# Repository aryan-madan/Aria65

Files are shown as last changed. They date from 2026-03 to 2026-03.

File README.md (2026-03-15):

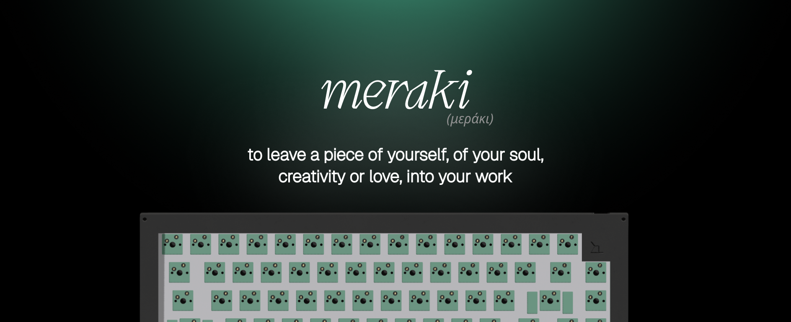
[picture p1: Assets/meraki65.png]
Banner


<p>
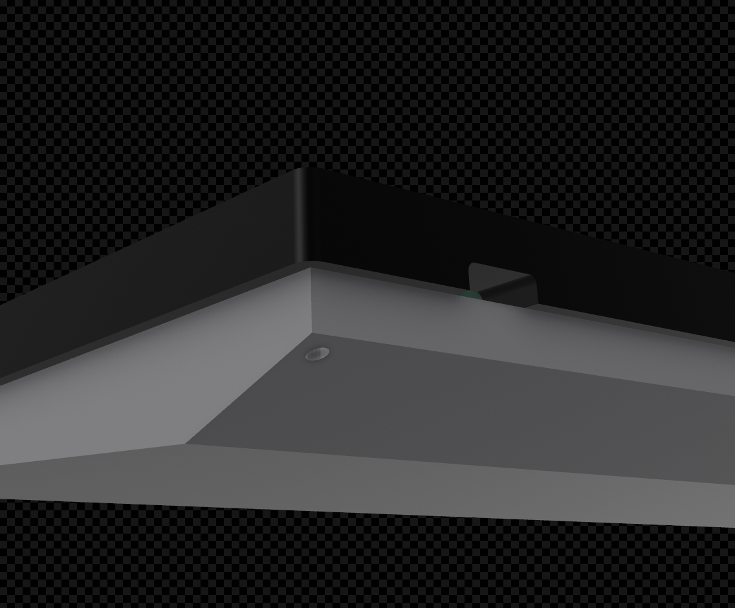
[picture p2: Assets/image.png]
  
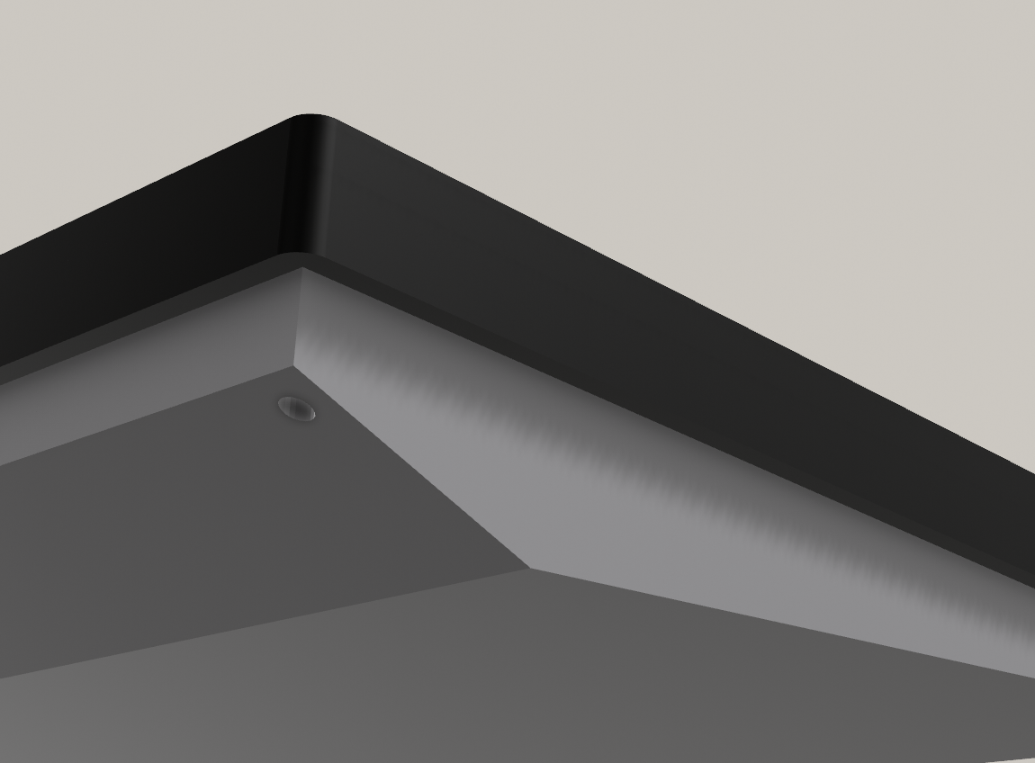
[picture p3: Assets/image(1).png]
  
</p>

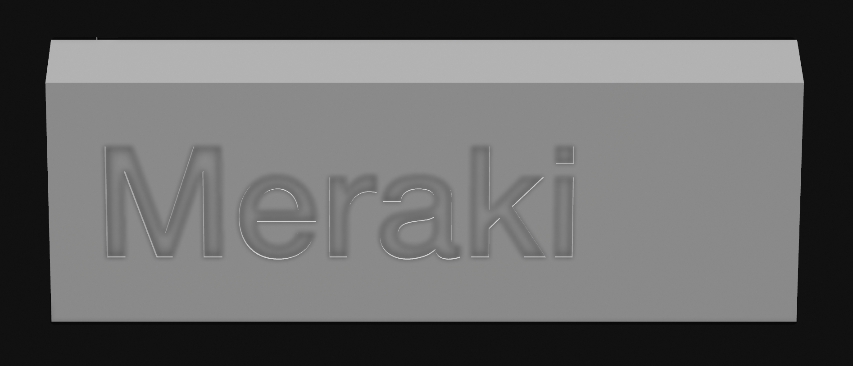
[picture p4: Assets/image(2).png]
Bottom


<p>
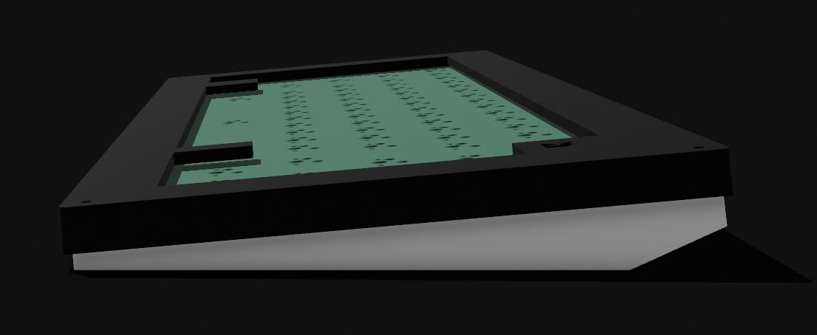
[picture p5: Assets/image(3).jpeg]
  
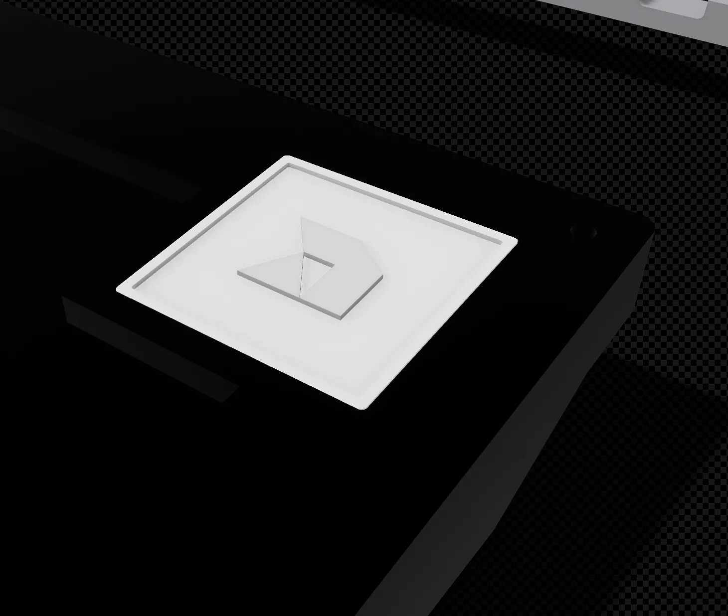
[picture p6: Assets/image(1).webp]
  
</p>

# Name

Meraki, is a greek word that means 'to do something with soul, creativity, or love; leaving a piece of yourself in what you do'.

# Layout 

The keyboard has a 65% WKL Layout. WKL stands for win-key-less, where the Windows key is removed from the keyboard, to give it a more symmetrical shape. WKL's are rarely seen in 65% form, which inspired me to make this board. I also opted for a blocker at the top right to fit the MCU.

# Firmware

The Meraki65 uses qmk for its firmware.
I also created a web-based software to re-map keys, called [Keydeck](https://keydeck.xyz).

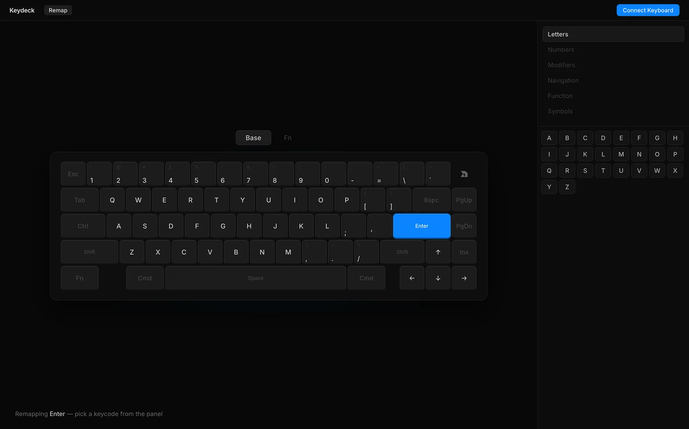
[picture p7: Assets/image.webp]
Keydeck Software


# PCB

## Schematic

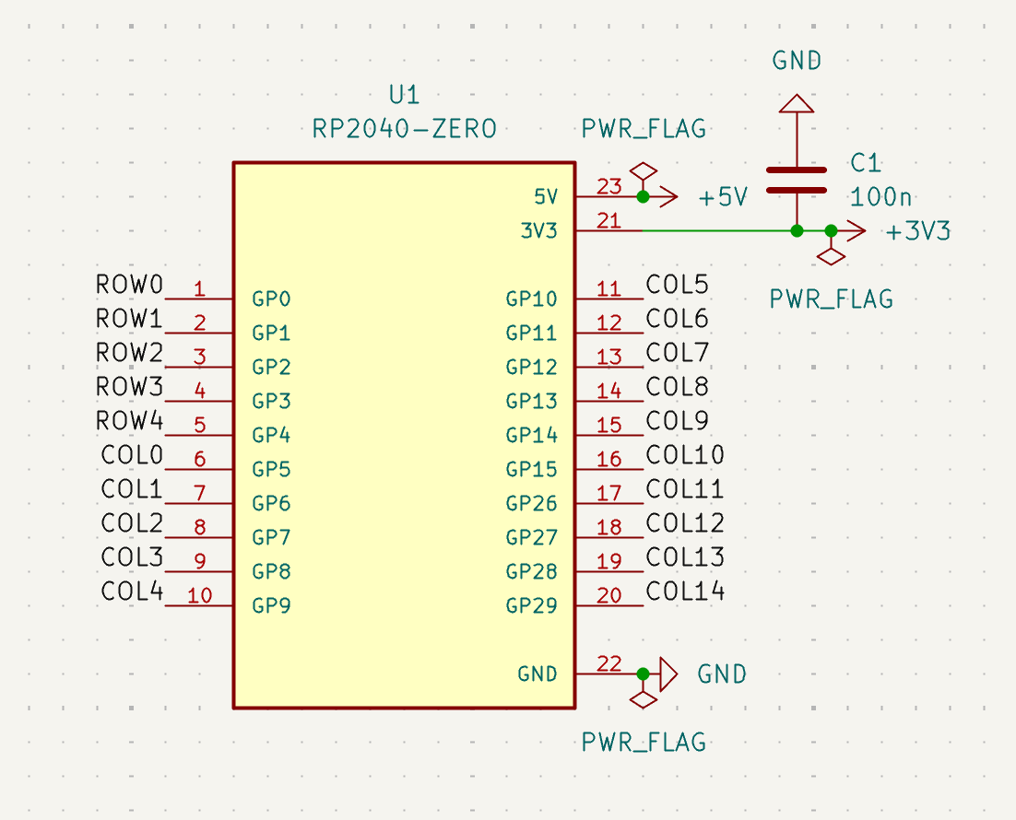
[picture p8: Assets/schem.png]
Schematic


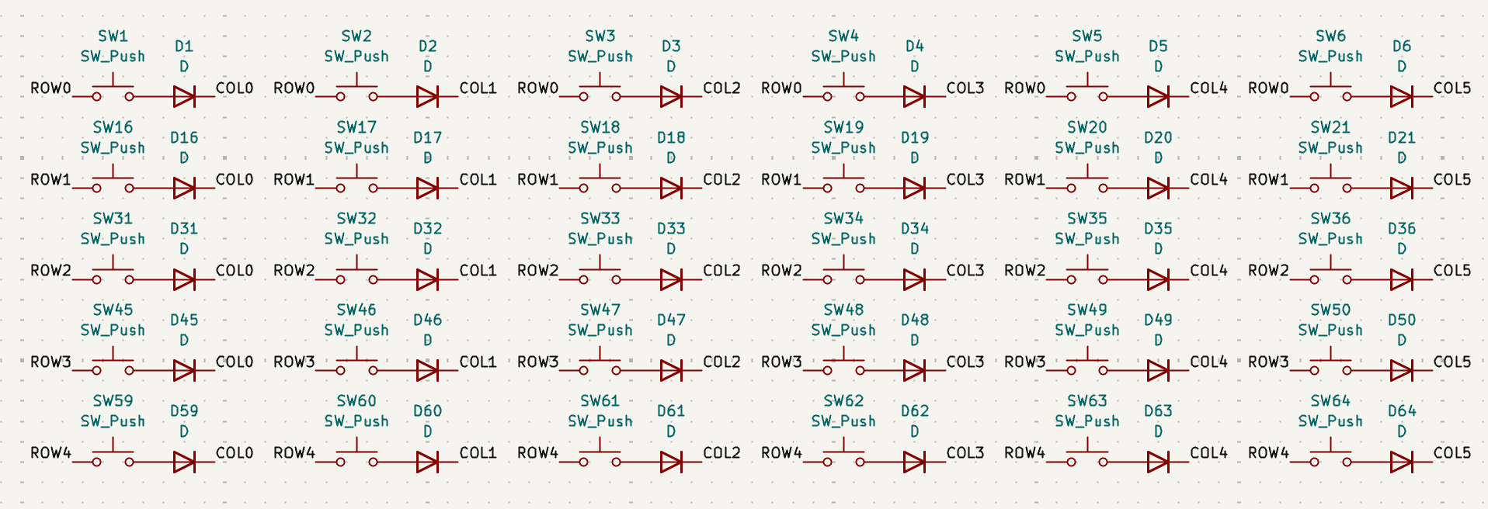
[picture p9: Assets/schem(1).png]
Schematic 2


## PCB

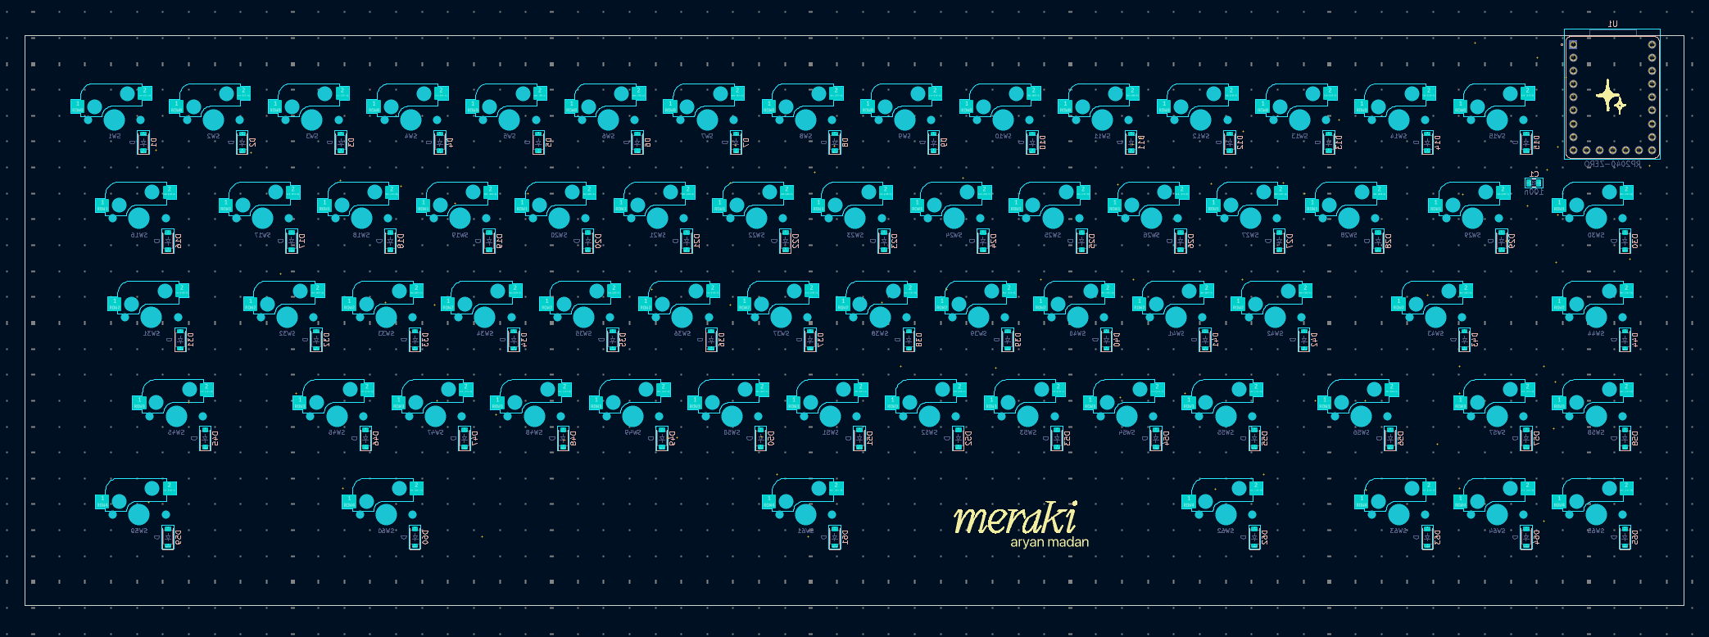
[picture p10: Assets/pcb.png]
PCB


# Bill of Materials

Total Cost: **9,792** (~$106.38 USD)

## Case

https://app.shapr3d.com/v/_-Txvu9VtqTR88f_0C18B

To be 3d printed by the Printing Legion.

## Parts

| Piece | Brand | Quantity | Cost (INR) | Cost (USD) | Link |
|---|---|---|---|---|---|
| Plate Mount Stabilizers | Durock | 1 set | 380 | ~$4.13 | [Link](https://www.genesispc.in/products/durock-plate-mount-stabilizers-6-25u-4x2u-black?variant=43129560924213) |
| Y2 Switches | Keygeek | 70 | 2240 | ~$24.35 | [Link](https://keyora.store/products/keygeek-y2-linear-switch) |
| Gummy-O-Ring Mount | NeoMacro | 1 | 650 | ~$7.00 | [Link](https://neomacro.in/products/neo65-spare-parts-pre-order?variant=46159065415958) |
| M2 x 12mm Screws | Generic | 2 | — | — | - |
| M2 x 10mm Screws | Generic | 2 | — | — | - |
| **Total** | | | **3522** | **~$38.22** | |

## PCB

| Part | Brand | Quantity | Cost (INR) | Cost (USD) | Link |
|---|---|---|---|---|---|
| Printing | JLCPCB | 5(min) | 3403 | ~$37.00 | [Link](https://jlcpcb.com/) |
| RP 2040 Zero | Robu | 1 | 235 | ~$2.55 | [Link](https://robu.in/product/rp2040-zero-for-raspberry-pi-microcontroller-with-soldering/) |
| Hotswap Sockets | Kailh | 100(min) | 532 | ~$5.78 | [Link](https://meckeys.com/shop/accessories/keyboard-accessories/key-switches/kailh-hot-swap-socket/) |
| Diodes | — | 100(min) | 100 | ~$1.09 | [Link](https://www.amazon.in/dp/B084ZP5BJ3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) |
| **Total** | | | **4270** | **~$46.42** | |

## Decoration

| Part | Brand | Quantity | Cost (INR) | Cost (USD) |
|---|---|---|---|---|
| Keycaps | Clones | 1 set | 2000 | ~$21.74 |
| **Total** | | | **2000** | **~$21.74** |

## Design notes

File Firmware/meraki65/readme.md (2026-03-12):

# meraki65

meraki65

*A short description of the keyboard/project*

* Keyboard Maintainer: [Aryan Madan](https://github.com/Aryan Madan)
* Hardware Supported: *The PCBs, controllers supported*
* Hardware Availability: *Links to where you can find this hardware*

Make example for this keyboard (after setting up your build environment):

    make meraki65:default

Flashing example for this keyboard:

    make meraki65:default:flash

See the [build environment setup](https://docs.qmk.fm/#/getting_started_build_tools) and the [make instructions](https://docs.qmk.fm/#/getting_started_make_guide) for more information. Brand new to QMK? Start with our [Complete Newbs Guide](https://docs.qmk.fm/#/newbs).

## Bootloader

Enter the bootloader in 3 ways:

* **Bootmagic reset**: Hold down the key at (0,0) in the matrix (usually the top left key or Escape) and plug in the keyboard
* **Physical reset button**: Briefly press the button on the back of the PCB - some may have pads you must short instead
* **Keycode in layout**: Press the key mapped to `QK_BOOT` if it is available

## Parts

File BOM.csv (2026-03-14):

Category | Part | Brand | Quantity | Cost (INR) | Cost (USD) | Link
Case | 3D Printed Case | Printing Legion | 1 | — | — | https://app.shapr3d.com/p/29c12f4c-3f33-421a-806f-35c27462d305
Parts | Plate Mount Stabilizers | Durock | 1 set | 380 | ~$4.13 | https://www.genesispc.in/products/durock-plate-mount-stabilizers-6-25u-4x2u-black?variant=43129560924213
Parts | Y2 Switches | Keygeek | 70 | 2240 | ~$24.35 | https://keyora.store/products/keygeek-y2-linear-switch
Parts | Gummy-O-Ring Mount | NeoMacro | 1 | 650 | ~$7.00 | https://neomacro.in/products/neo65-spare-parts-pre-order?variant=46159065415958
Parts | M2 x 12mm Screws | Generic | 2 | — | — | —
Parts | M2 x 10mm Screws | Generic | 2 | — | — | —
Parts | SUBTOTAL |  |  | 3522 | ~$38.22
PCB | Printing | JLCPCB | 5 (min) | 3403 | ~$37.00 | https://jlcpcb.com/
PCB | RP 2040 Zero | Robu | 1 | 235 | ~$2.55 | https://robu.in/product/rp2040-zero-for-raspberry-pi-microcontroller-with-soldering/
PCB | Hotswap Sockets | Kailh | 100 (min) | 532 | ~$5.78 | https://meckeys.com/shop/accessories/keyboard-accessories/key-switches/kailh-hot-swap-socket/
PCB | Diodes | — | 100 (min) | 100 | ~$1.09 | https://www.amazon.in/dp/B084ZP5BJ3
PCB | SUBTOTAL |  |  | 4270 | ~$46.42
Decoration | Keycaps | Clones | 1 set | 2000 | ~$21.74 | —
Decoration | SUBTOTAL |  |  | 2000 | ~$21.74
 | TOTAL |  |  | 9792 | ~$106.38

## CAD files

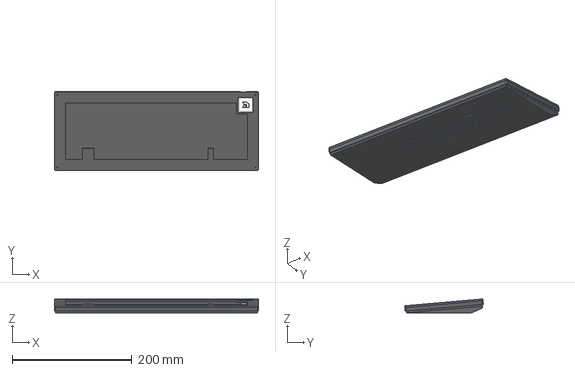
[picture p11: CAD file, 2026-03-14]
CAD/Assembled.step
340.8 x 131.5 x 23.7 mm

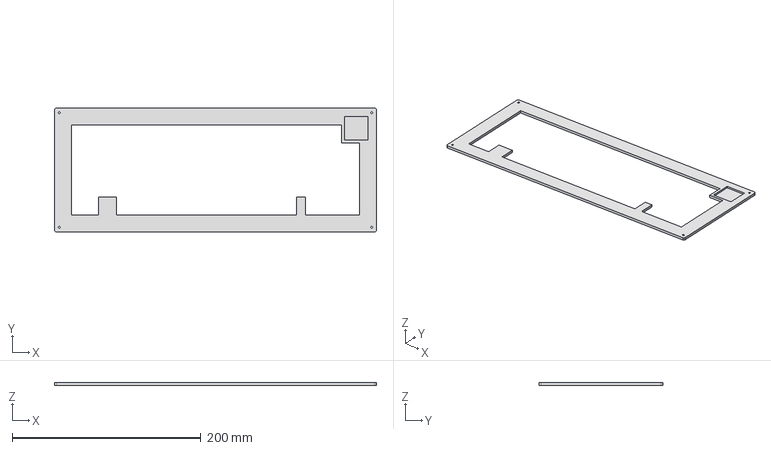
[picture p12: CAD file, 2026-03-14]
CAD/Top Frame.step
340.8 x 131.2 x 3.00 mm

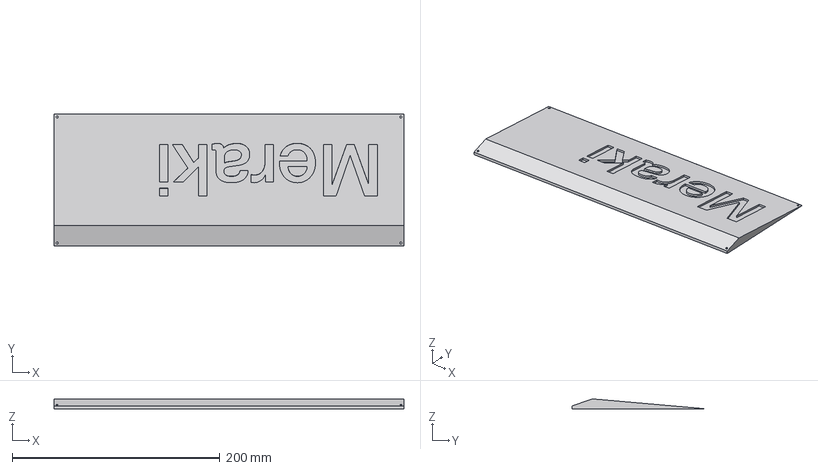
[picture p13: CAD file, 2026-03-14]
CAD/Base.step
336.8 x 127.2 x 9.82 mm

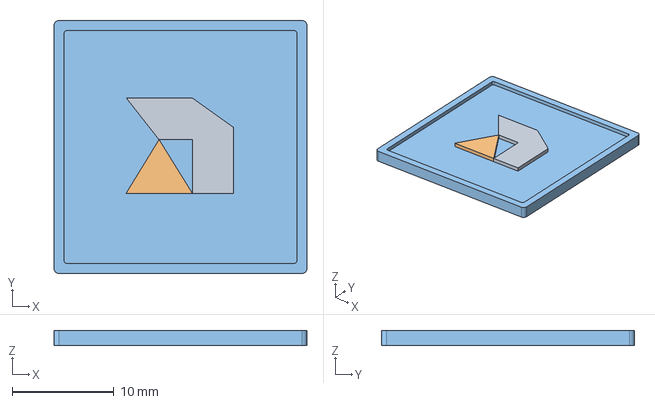
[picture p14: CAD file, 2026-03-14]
CAD/Badge.step
24.9 x 24.9 x 1.50 mm

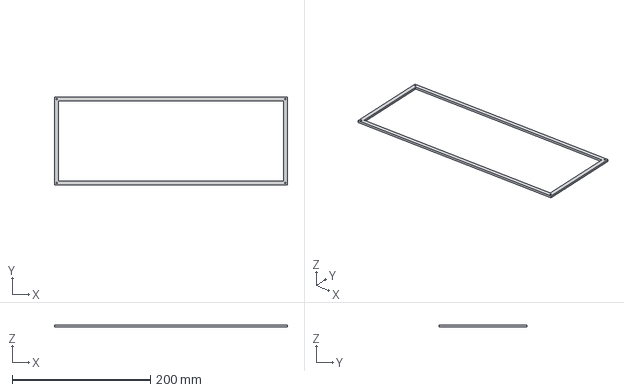
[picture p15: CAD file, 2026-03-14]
CAD/Bottom Frame.step
336.8 x 127.2 x 3.00 mm

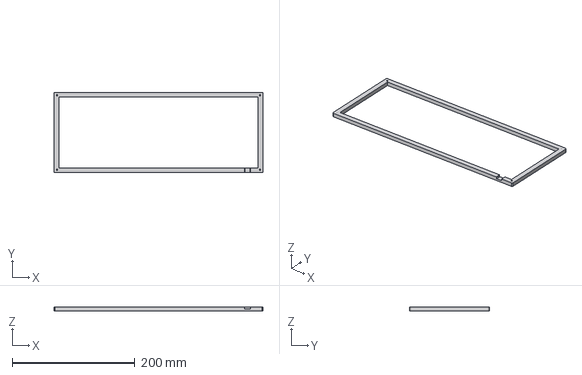
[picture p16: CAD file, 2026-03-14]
CAD/Middle Frame.step
340.8 x 131.2 x 6.00 mm

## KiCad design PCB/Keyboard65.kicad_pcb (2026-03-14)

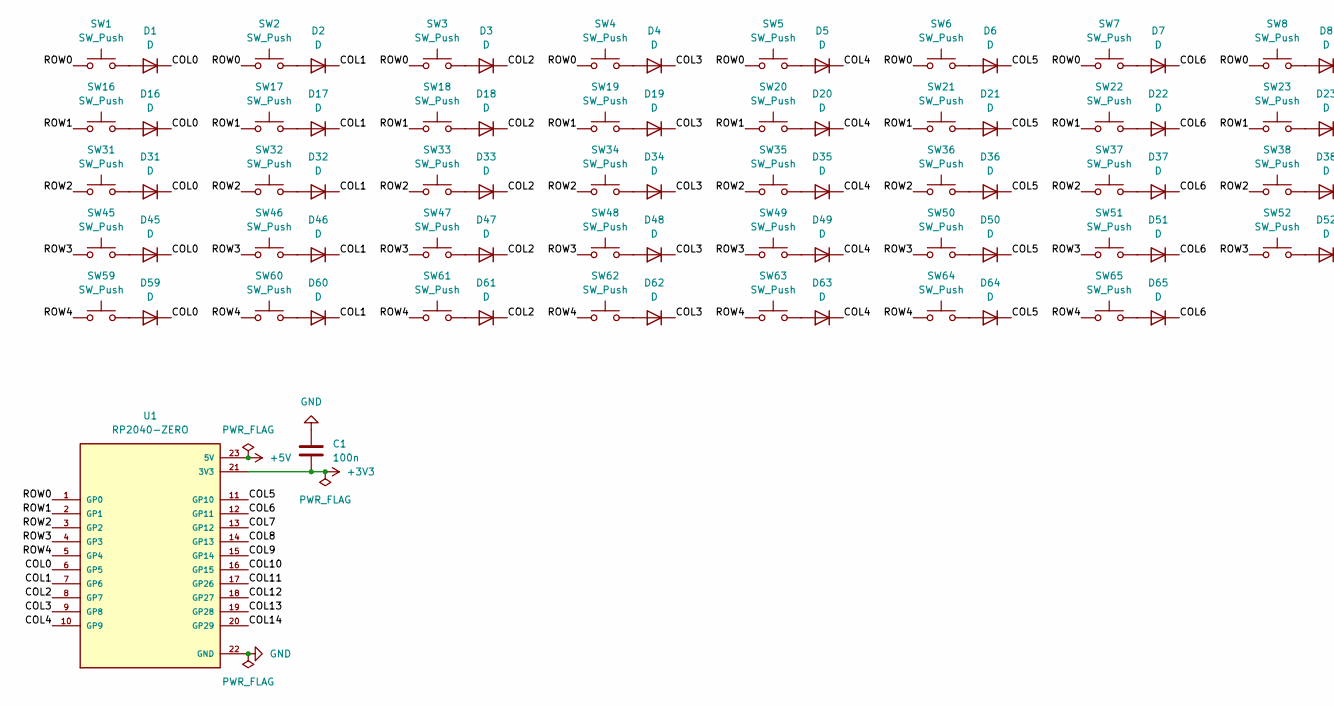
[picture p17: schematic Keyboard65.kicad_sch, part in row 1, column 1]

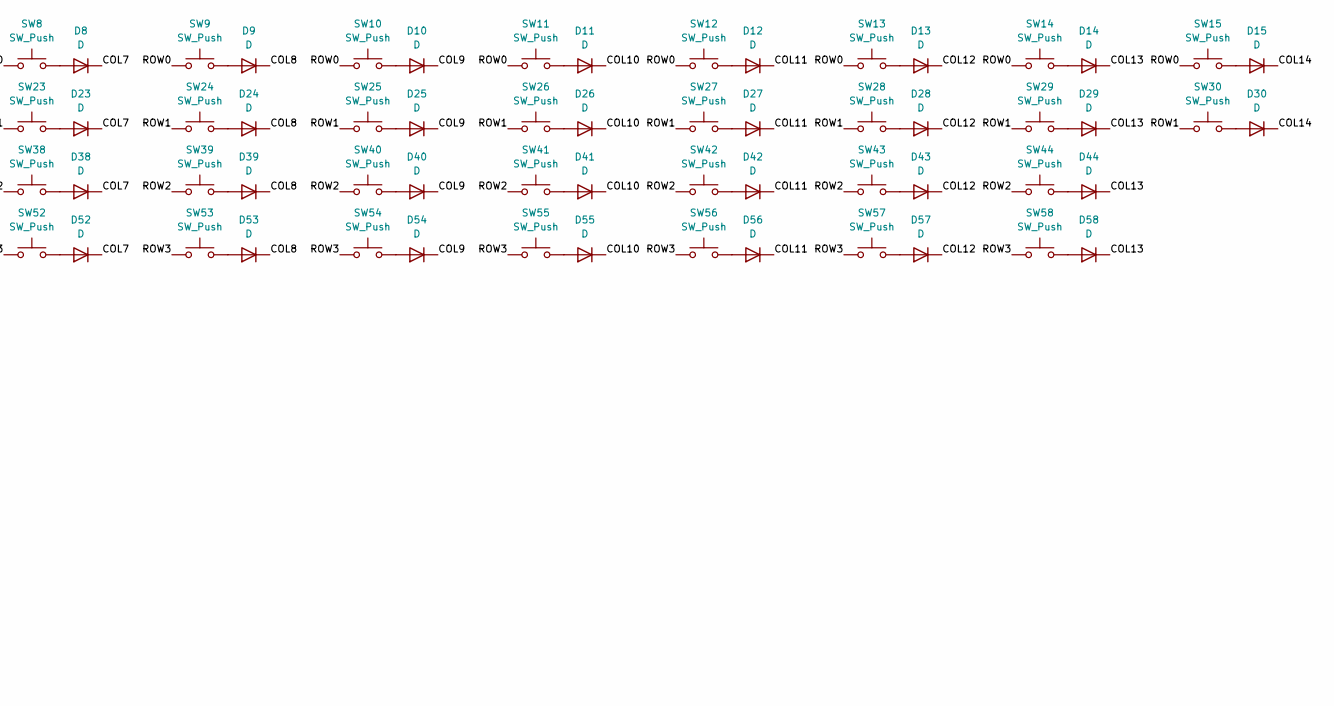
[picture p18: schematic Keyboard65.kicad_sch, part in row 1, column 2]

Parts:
C1: 100n; C_0805_2012Metric
D1, D2, D3, D4, D5, D6, D7, D8, D9, D10, D11, D12, D13, D14, D15, D16, D17, D18, D19, D20, D21, D22, D23, D24, D25, D26, D27, D28, D29, D30, D31, D32, D33, D34, D35, D36, D37, D38, D39, D40, D41, D42, D43, D44, D45, D46, D47, D48, D49, D50, D51, D52, D53, D54, D55, D56, D57, D58, D59, D60, D61, D62, D63, D64, D65: D; D_SOD-123
SW1, SW2, SW3, SW4, SW5, SW6, SW7, SW8, SW9, SW10, SW11, SW12, SW13, SW14, SW15, SW16, SW17, SW18, SW19, SW20, SW21, SW22, SW23, SW24, SW25, SW26, SW27, SW28, SW29, SW30, SW31, SW32, SW33, SW34, SW35, SW36, SW37, SW38, SW39, SW40, SW41, SW42, SW43, SW44, SW45, SW46, SW47, SW48, SW49, SW50, SW51, SW52, SW53, SW54, SW55, SW56, SW57, SW58, SW59, SW60, SW61, SW62, SW63, SW64, SW65: SW_Push; MX-Hotswap-1U
U1: RP2040-ZERO; MODULE_RP2040-ZERO; PARTREV NA

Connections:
+3V3: C1.1, U1.21 (3V3)
+5V: U1.23 (5V)
/COL0: D1.1 (K), D16.1 (K), D31.1 (K), D45.1 (K), D59.1 (K), U1.6 (GP5)
/COL1: D2.1 (K), D17.1 (K), D32.1 (K), D46.1 (K), D60.1 (K), U1.7 (GP6)
/COL2: D3.1 (K), D18.1 (K), D33.1 (K), D47.1 (K), D61.1 (K), U1.8 (GP7)
/COL3: D4.1 (K), D19.1 (K), D34.1 (K), D48.1 (K), D62.1 (K), U1.9 (GP8)
/COL4: D5.1 (K), D20.1 (K), D35.1 (K), D49.1 (K), D63.1 (K), U1.10 (GP9)
/COL5: D6.1 (K), D21.1 (K), D36.1 (K), D50.1 (K), D64.1 (K), U1.11 (GP10)
/COL6: D7.1 (K), D22.1 (K), D37.1 (K), D51.1 (K), D65.1 (K), U1.12 (GP11)
/COL7: D8.1 (K), D23.1 (K), D38.1 (K), D52.1 (K), U1.13 (GP12)
/COL8: D9.1 (K), D24.1 (K), D39.1 (K), D53.1 (K), U1.14 (GP13)
/COL9: D10.1 (K), D25.1 (K), D40.1 (K), D54.1 (K), U1.15 (GP14)
/COL10: D11.1 (K), D26.1 (K), D41.1 (K), D55.1 (K), U1.16 (GP15)
/COL11: D12.1 (K), D27.1 (K), D42.1 (K), D56.1 (K), U1.17 (GP26)
/COL12: D13.1 (K), D28.1 (K), D43.1 (K), D57.1 (K), U1.18 (GP27)
/COL13: D14.1 (K), D29.1 (K), D44.1 (K), D58.1 (K), U1.19 (GP28)
/COL14: D15.1 (K), D30.1 (K), U1.20 (GP29)
/ROW0: SW1.1, SW2.1, SW3.1, SW4.1, SW5.1, SW6.1, SW7.1, SW8.1, SW9.1, SW10.1, SW11.1, SW12.1, SW13.1, SW14.1, SW15.1, U1.1 (GP0)
/ROW1: SW16.1, SW17.1, SW18.1, SW19.1, SW20.1, SW21.1, SW22.1, SW23.1, SW24.1, SW25.1, SW26.1, SW27.1, SW28.1, SW29.1, SW30.1, U1.2 (GP1)
/ROW2: SW31.1, SW32.1, SW33.1, SW34.1, SW35.1, SW36.1, SW37.1, SW38.1, SW39.1, SW40.1, SW41.1, SW42.1, SW43.1, SW44.1, U1.3 (GP2)
/ROW3: SW45.1, SW46.1, SW47.1, SW48.1, SW49.1, SW50.1, SW51.1, SW52.1, SW53.1, SW54.1, SW55.1, SW56.1, SW57.1, SW58.1, U1.4 (GP3)
/ROW4: SW59.1, SW60.1, SW61.1, SW62.1, SW63.1, SW64.1, SW65.1, U1.5 (GP4)
GND: C1.2, U1.22 (GND)
unnamed: D1.2 (A), SW1.2
unnamed: D2.2 (A), SW2.2
unnamed: D3.2 (A), SW3.2
unnamed: D4.2 (A), SW4.2
unnamed: D5.2 (A), SW5.2
unnamed: D6.2 (A), SW6.2
unnamed: D7.2 (A), SW7.2
unnamed: D8.2 (A), SW8.2
unnamed: D9.2 (A), SW9.2
unnamed: D10.2 (A), SW10.2
unnamed: D11.2 (A), SW11.2
unnamed: D12.2 (A), SW12.2
unnamed: D13.2 (A), SW13.2
unnamed: D14.2 (A), SW14.2
unnamed: D15.2 (A), SW15.2
unnamed: D16.2 (A), SW16.2
unnamed: D17.2 (A), SW17.2
unnamed: D18.2 (A), SW18.2
unnamed: D19.2 (A), SW19.2
unnamed: D20.2 (A), SW20.2
unnamed: D21.2 (A), SW21.2
unnamed: D22.2 (A), SW22.2
unnamed: D23.2 (A), SW23.2
unnamed: D24.2 (A), SW24.2
unnamed: D25.2 (A), SW25.2
unnamed: D26.2 (A), SW26.2
unnamed: D27.2 (A), SW27.2
unnamed: D28.2 (A), SW28.2
unnamed: D29.2 (A), SW29.2
unnamed: D30.2 (A), SW30.2
unnamed: D31.2 (A), SW31.2
unnamed: D32.2 (A), SW32.2
unnamed: D33.2 (A), SW33.2
unnamed: D34.2 (A), SW34.2
unnamed: D35.2 (A), SW35.2
unnamed: D36.2 (A), SW36.2
unnamed: D37.2 (A), SW37.2
unnamed: D38.2 (A), SW38.2
unnamed: D39.2 (A), SW39.2
unnamed: D40.2 (A), SW40.2
unnamed: D41.2 (A), SW41.2
unnamed: D42.2 (A), SW42.2
unnamed: D43.2 (A), SW43.2
unnamed: D44.2 (A), SW44.2
unnamed: D45.2 (A), SW45.2
unnamed: D46.2 (A), SW46.2
unnamed: D47.2 (A), SW47.2
unnamed: D48.2 (A), SW48.2
unnamed: D49.2 (A), SW49.2
unnamed: D50.2 (A), SW50.2
unnamed: D51.2 (A), SW51.2
unnamed: D52.2 (A), SW52.2
unnamed: D53.2 (A), SW53.2
unnamed: D54.2 (A), SW54.2
unnamed: D55.2 (A), SW55.2
unnamed: D56.2 (A), SW56.2
unnamed: D57.2 (A), SW57.2
unnamed: D58.2 (A), SW58.2
unnamed: D59.2 (A), SW59.2
unnamed: D60.2 (A), SW60.2
unnamed: D61.2 (A), SW61.2
unnamed: D62.2 (A), SW62.2
unnamed: D63.2 (A), SW63.2
unnamed: D64.2 (A), SW64.2
unnamed: D65.2 (A), SW65.2

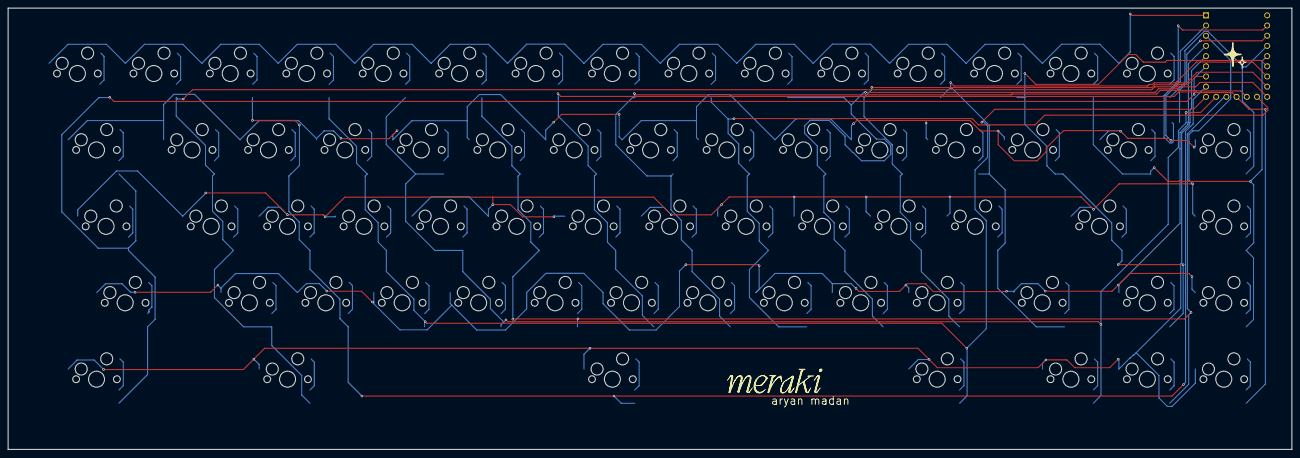
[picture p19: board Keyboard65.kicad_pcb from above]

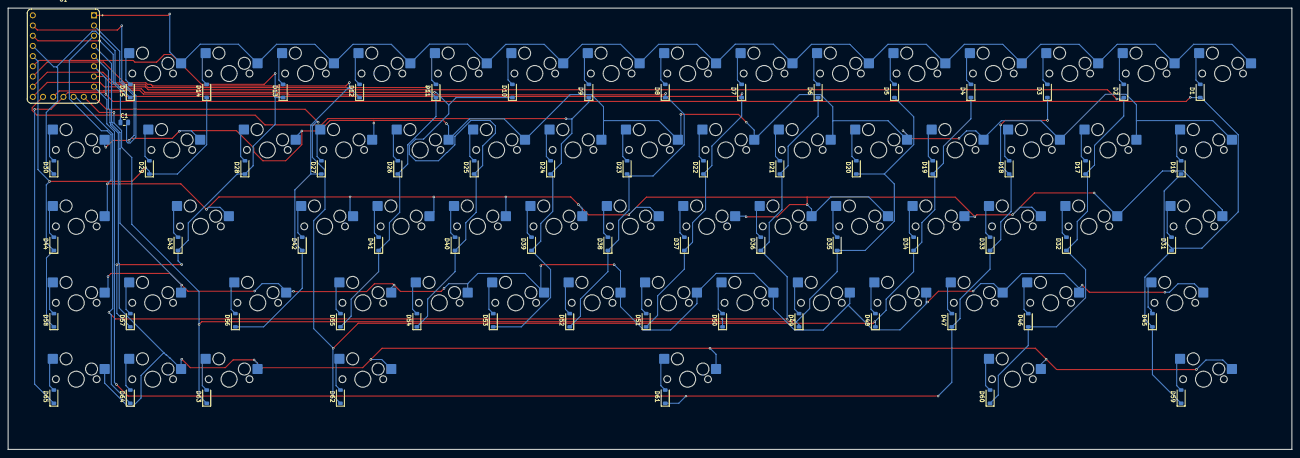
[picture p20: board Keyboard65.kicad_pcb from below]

Board: 2 copper layers, 320.0 x 110.0 mm, 132 parts (132 on the bottom side), 87 nets.

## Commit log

2026-03-06 [1] Making the schematics
    [Keyboard65.kicad_sch]
2026-03-08 [2] I hate routing traces
    [Keyboard65.kicad_pcb]
2026-03-08 [3] Modeling the case
2026-03-12 [5] Complete overhaul
    [Base.stl, Bottom Frame.stl, Keyboard65.kicad_pcb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]
2026-03-12 Added case in README.md
2026-03-13 Updated README.md with correct BOM
2026-03-14 [5] Finishing touches
    [Assembled.step, Badge.step, Base.step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]
2026-03-14 Added BOM.csv file
    [BOM.csv]
2026-03-14 Update the silkscreen and the PCB files
    [Keyboard65.kicad_pcb]
2026-03-14 Added project file link and qty field in BOM
    [BOM.csv]
